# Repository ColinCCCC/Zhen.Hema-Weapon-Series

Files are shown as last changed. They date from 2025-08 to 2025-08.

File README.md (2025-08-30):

# 兵击武器系列『震』

## 声明

本项目遵循[MIT协议](https://mitsloan.mit.edu/licensing)，允许自由使用、复制、修改、合并、发布、分发和商业化。

不保障项目绝对安全，使用本项目请自负一切后果。

本项目为减伤体育用品设计，请勿用于违反法律法规用途。

## 成品说明

本项目为用于兵击对练的武器系列设计，计划包含腰刀、打刀、单手德砍、侧剑等。系列设计主题风格为激进、锐利的近未来工业风格。

刀身无渐薄，项目通过直接设计刀身形状，以符合真刀质量分布，并达成减伤要求。

### 腰刀





- 全长97cm，柄长20cm（含刀首）。采用70%petg打印剑柄并打磨装配后，总重约800g，重心位于镡前约13.5cm。

- 经测试，若选用3mm65Mn或60Si2Mn板材，剑条刺弯压力约10kg。

- 数据可能存在浮动，视选材与工艺而定。

#### 切割件

在淘宝等电商应用，搜索并查找提供**65Mn板材激光切割定制**服务的商家，按需选择合适的商品页面，并联系客服。

为商家提供所需的**DXF文件**，按需求说明**每个文件的切割的数量与厚度**，待商家报价后，支付并提供收货地址，即可等待切割成品送达。

*所需DXF文件及其对应厚度如下：*

- 刀条【3mm】：[zhen_blade.DXF](https://github.com/ColinCCCC/Zhen.Hema-Weapon-Series/blob/main/mingWaistSaber/zhen_blade.DXF)

- 刀镞【3mm】：[zhen-zu.DXF](https://github.com/ColinCCCC/Zhen.Hema-Weapon-Series/blob/main/mingWaistSaber/zhen_zu.DXF)

- 刀首（中片）【3mm】：[zhen_weight_mid.DXF](https://github.com/ColinCCCC/Zhen.Hema-Weapon-Series/blob/main/mingWaistSaber/zhen_weight_mid.SLDPRT)

- 刀首（侧片）【3mm，6个】：[zhen_weight_side.DXF](https://github.com/ColinCCCC/Zhen.Hema-Weapon-Series/blob/main/mingWaistSaber/zhen_weight_side.DXF)

- 刀镡【4mm】：[zhen_hgrd.DXF](https://github.com/ColinCCCC/Zhen.Hema-Weapon-Series/blob/main/mingWaistSaber/zhen_hgrd.DXF)

#### 打印件

若自备3D打印机，可以自行下载项目中的**STL文件**进行切片打印。

若无3D打印机，可在闲鱼搜索附近提供3D打印服务的商户，提供项目中的**STL文件**，打印后取货。

- 刀柄（左片）：[zhen_hdl_l.STL](https://github.com/ColinCCCC/Zhen.Hema-Weapon-Series/blob/main/mingWaistSaber/zhen_hdl_l.STL)

- 刀柄（右片）：[zhen_hdl_r.STL](https://github.com/ColinCCCC/Zhen.Hema-Weapon-Series/blob/main/mingWaistSaber/zhen_hdl_r.STL)

#### 装配

采用3个M6\*14、1个M3\*8的夹板螺母固定，请自行购置

### 打刀（未完工）





- 全长105cm，柄长28cm。采用70%petg打印剑柄并打磨装配后，总重约860g，重心位于镡前约12.4cm。

- 经测试，若选用3mm65Mn或60Si2Mn板材，剑条刺弯压力约12kg。

- 数据可能存在浮动，视选材与工艺而定。

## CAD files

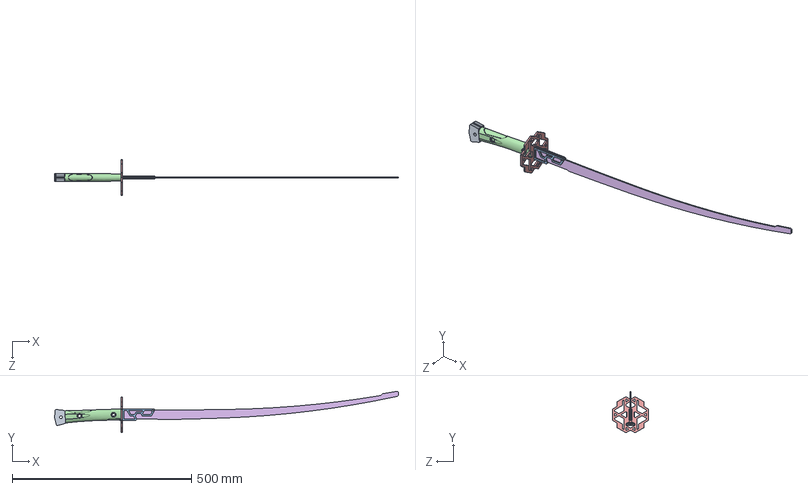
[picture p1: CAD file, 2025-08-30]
mingWaistSaber/mingWaistSaber.SLDASM
959.9 x 115.3 x 100.0 mm
zhen_blade
zhen_hgrd
zhen_hdl
zhen_zu x 2
zhen_weight_mid
zhen_weight_side x 6

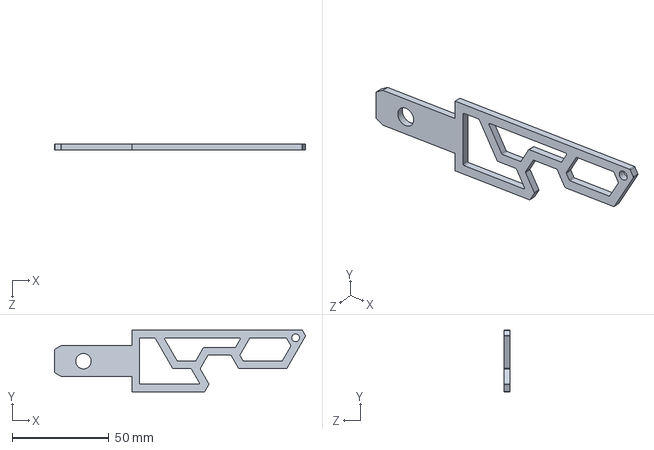
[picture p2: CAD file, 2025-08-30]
mingWaistSaber/zhen_zu.SLDPRT
129.9 x 32.0 x 3.00 mm

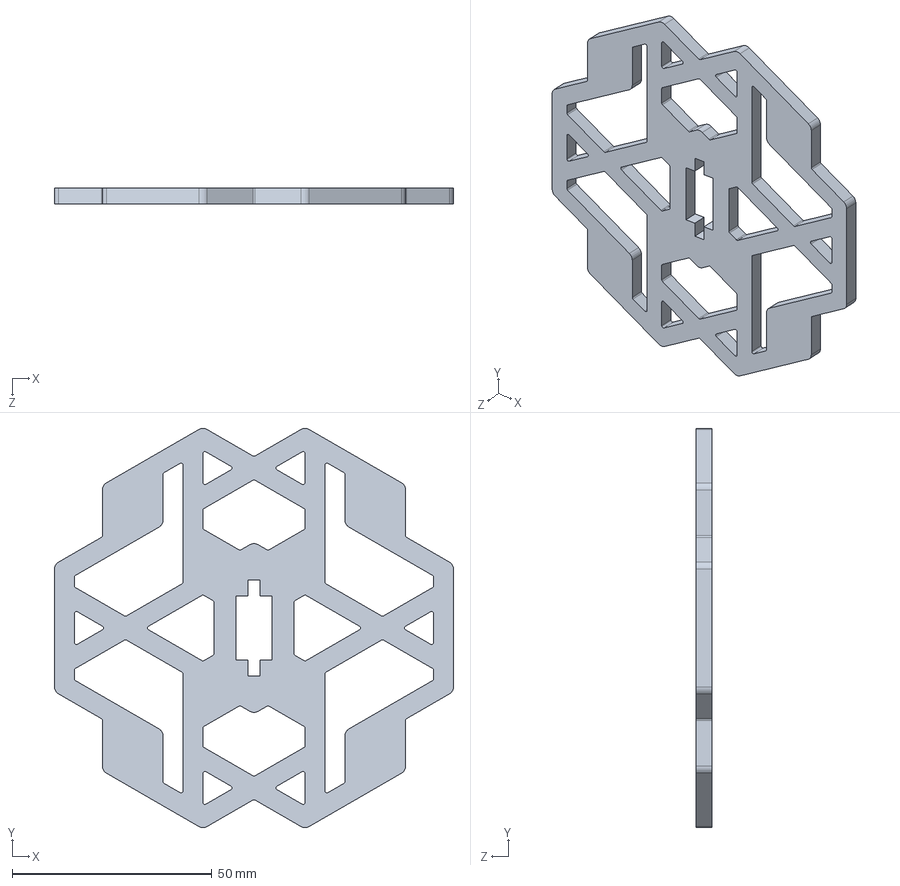
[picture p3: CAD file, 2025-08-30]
mingWaistSaber/zhen_hgrd.SLDPRT
100.0 x 100.1 x 4.00 mm

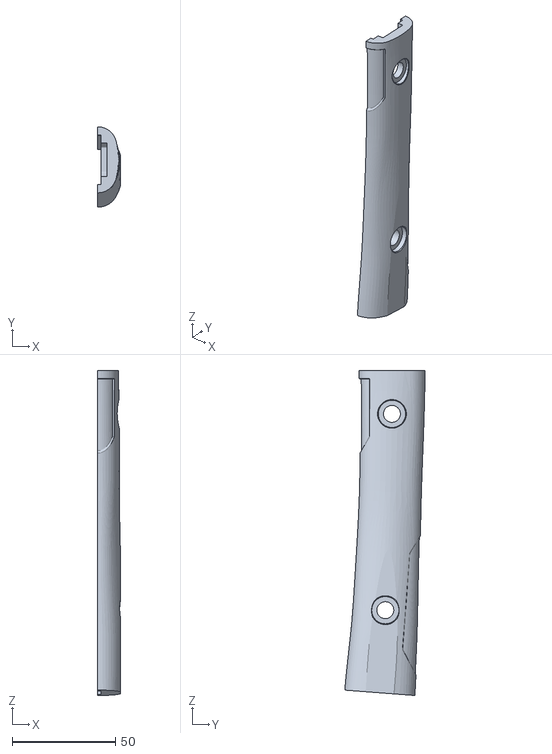
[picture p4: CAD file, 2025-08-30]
mingWaistSaber/zhen_hdl_l.STL
11.0 x 39.0 x 157.3

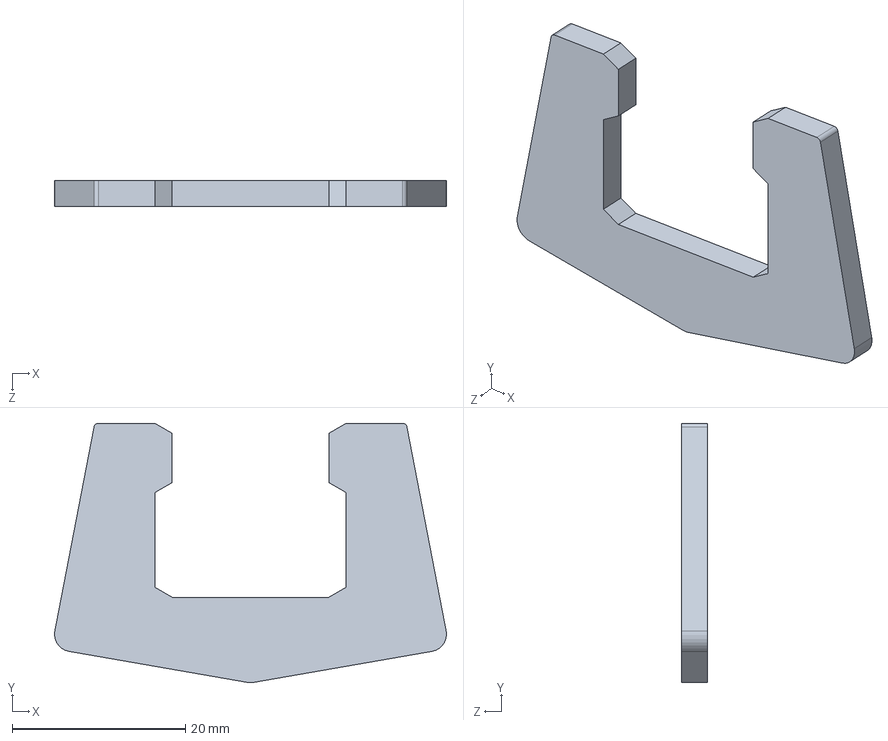
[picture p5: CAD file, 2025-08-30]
mingWaistSaber/zhen_weight_mid.SLDPRT
45.3 x 30.0 x 3.00 mm

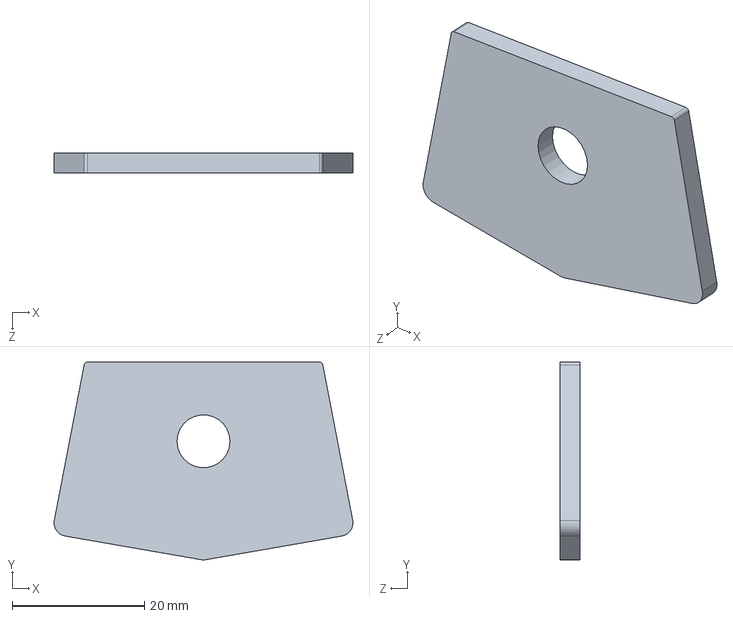
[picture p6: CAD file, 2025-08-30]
mingWaistSaber/zhen_weight_side.SLDPRT
45.3 x 30.0 x 3.00 mm

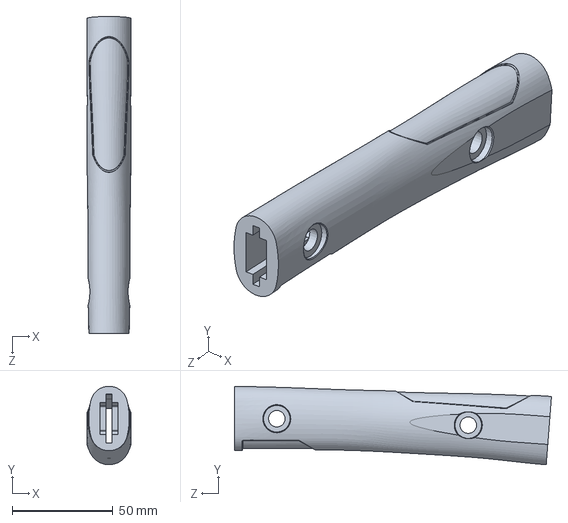
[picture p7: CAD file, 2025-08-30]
mingWaistSaber/zhen_hdl.SLDPRT
22.0 x 38.9 x 157.3 mm

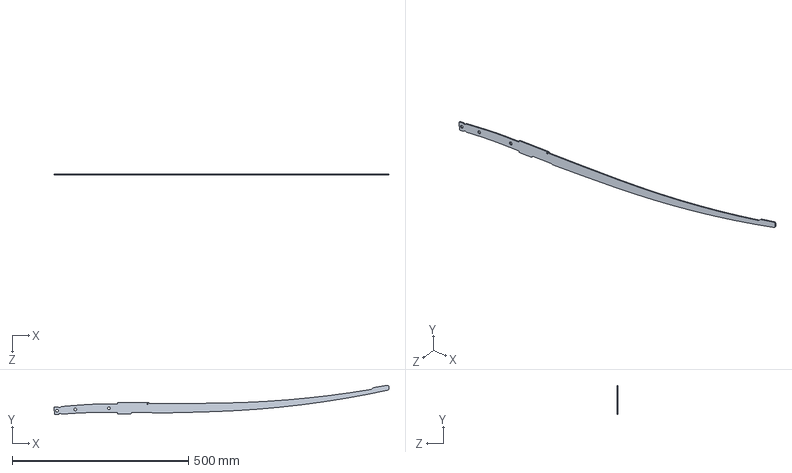
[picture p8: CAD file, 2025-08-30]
mingWaistSaber/zhen_blade.SLDPRT
950.6 x 83.7 x 3.00 mm

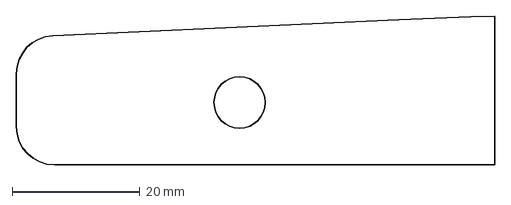
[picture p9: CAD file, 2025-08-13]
mingWaistSaber/zhen_weight.DXF
75.0 x 23.3 mm

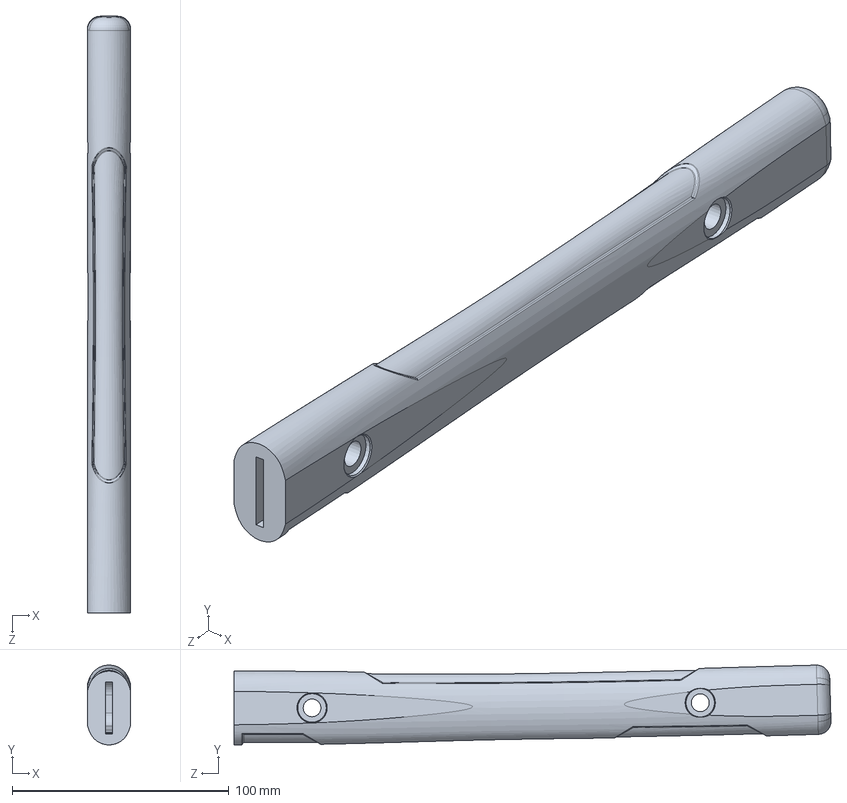
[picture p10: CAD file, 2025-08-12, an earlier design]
katana/zhen_hdl.SLDPRT
20.0 x 36.8 x 275.3 mm

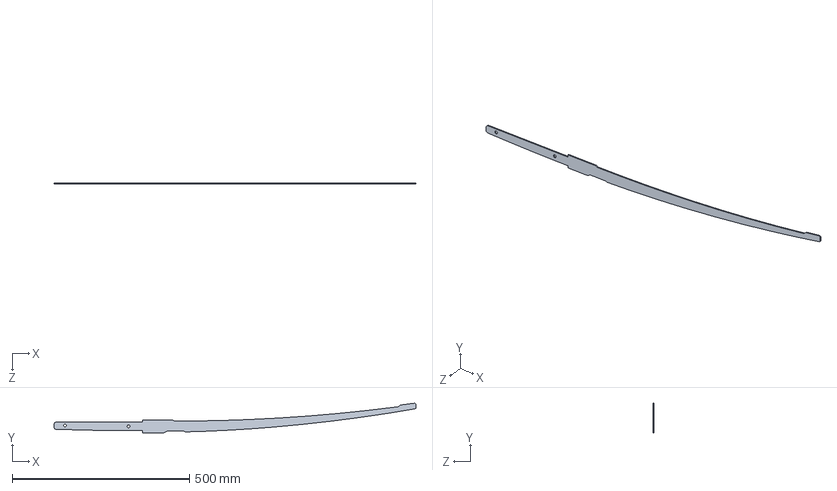
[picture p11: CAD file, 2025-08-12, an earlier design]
katana/zhen_blade.SLDPRT
1020.0 x 83.4 x 3.00 mm

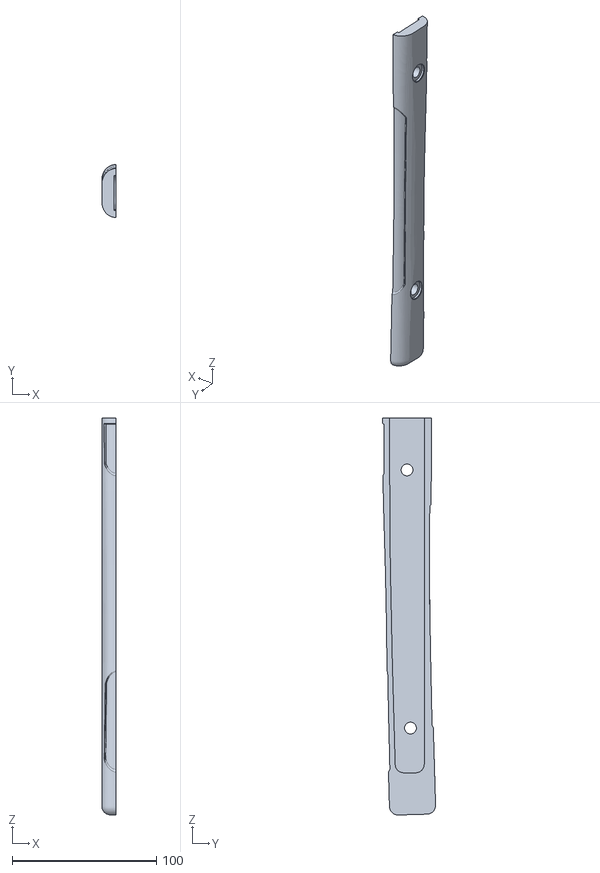
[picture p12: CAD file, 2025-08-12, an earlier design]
katana/zhen_hdl_r.STL
10.00 x 36.8 x 275.3

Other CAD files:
mingWaistSaber/zhen_hdl_r.STL
katana/zhen_hdl_l.STL
katana/zhen_blade.DXF
mingWaistSaber/zhen_blade.DXF
mingWaistSaber/zhen_hgrd.DXF
mingWaistSaber/zhen_weight_mid.DXF
mingWaistSaber/zhen_weight_side.DXF
mingWaistSaber/zhen_zu.DXF

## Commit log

2025-08-12 edit paths
    [zhen_blade.DXF, zhen_blade.SLDPRT, zhen_hdl.SLDPRT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]
2025-08-30 changed designs
    [mingWaistSaber.SLDASM, zhen_blade.SLDPRT, zhen_hdl.SLDPRT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]
